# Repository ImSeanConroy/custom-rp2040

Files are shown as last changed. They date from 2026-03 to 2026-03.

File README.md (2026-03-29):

# Custom RP2040

Complete design files for an RP2040 microcontroller-based board, created using KiCad.

## Contributing

Contributions are welcome. Please open an issue or fork the repository, create a new branch (`feature/your-feature-name`) and submit a pull request for any enhancements or bug fixes.

## License

This project is licensed under the MIT License - see the [LICENSE](LICENSE) file for information.

## Support

If you are having problems, please let me know by [raising a new issue](https://github.com/ImSeanConroy/custom-rp2040/issues/new/choose).

## Acknowledgments

A special thanks to the creators of these invaluable resources that helped guide this project:

- [Custom RP2040 PCB Design in KiCAD](https://deepbluembedded.com/raspberry-pi-pico-rp2040-schematic-pcb-design-in-kicad/): Raspberry Pi Pico (RP2040) Schematic & PCB Design in KiCAD by Khaled Magdy
- [Hardware design for the RP2040](https://github.com/calliah333/RP2040-designguide/tree/main?tab=readme-ov-file#voltage-regulator): by calliah333

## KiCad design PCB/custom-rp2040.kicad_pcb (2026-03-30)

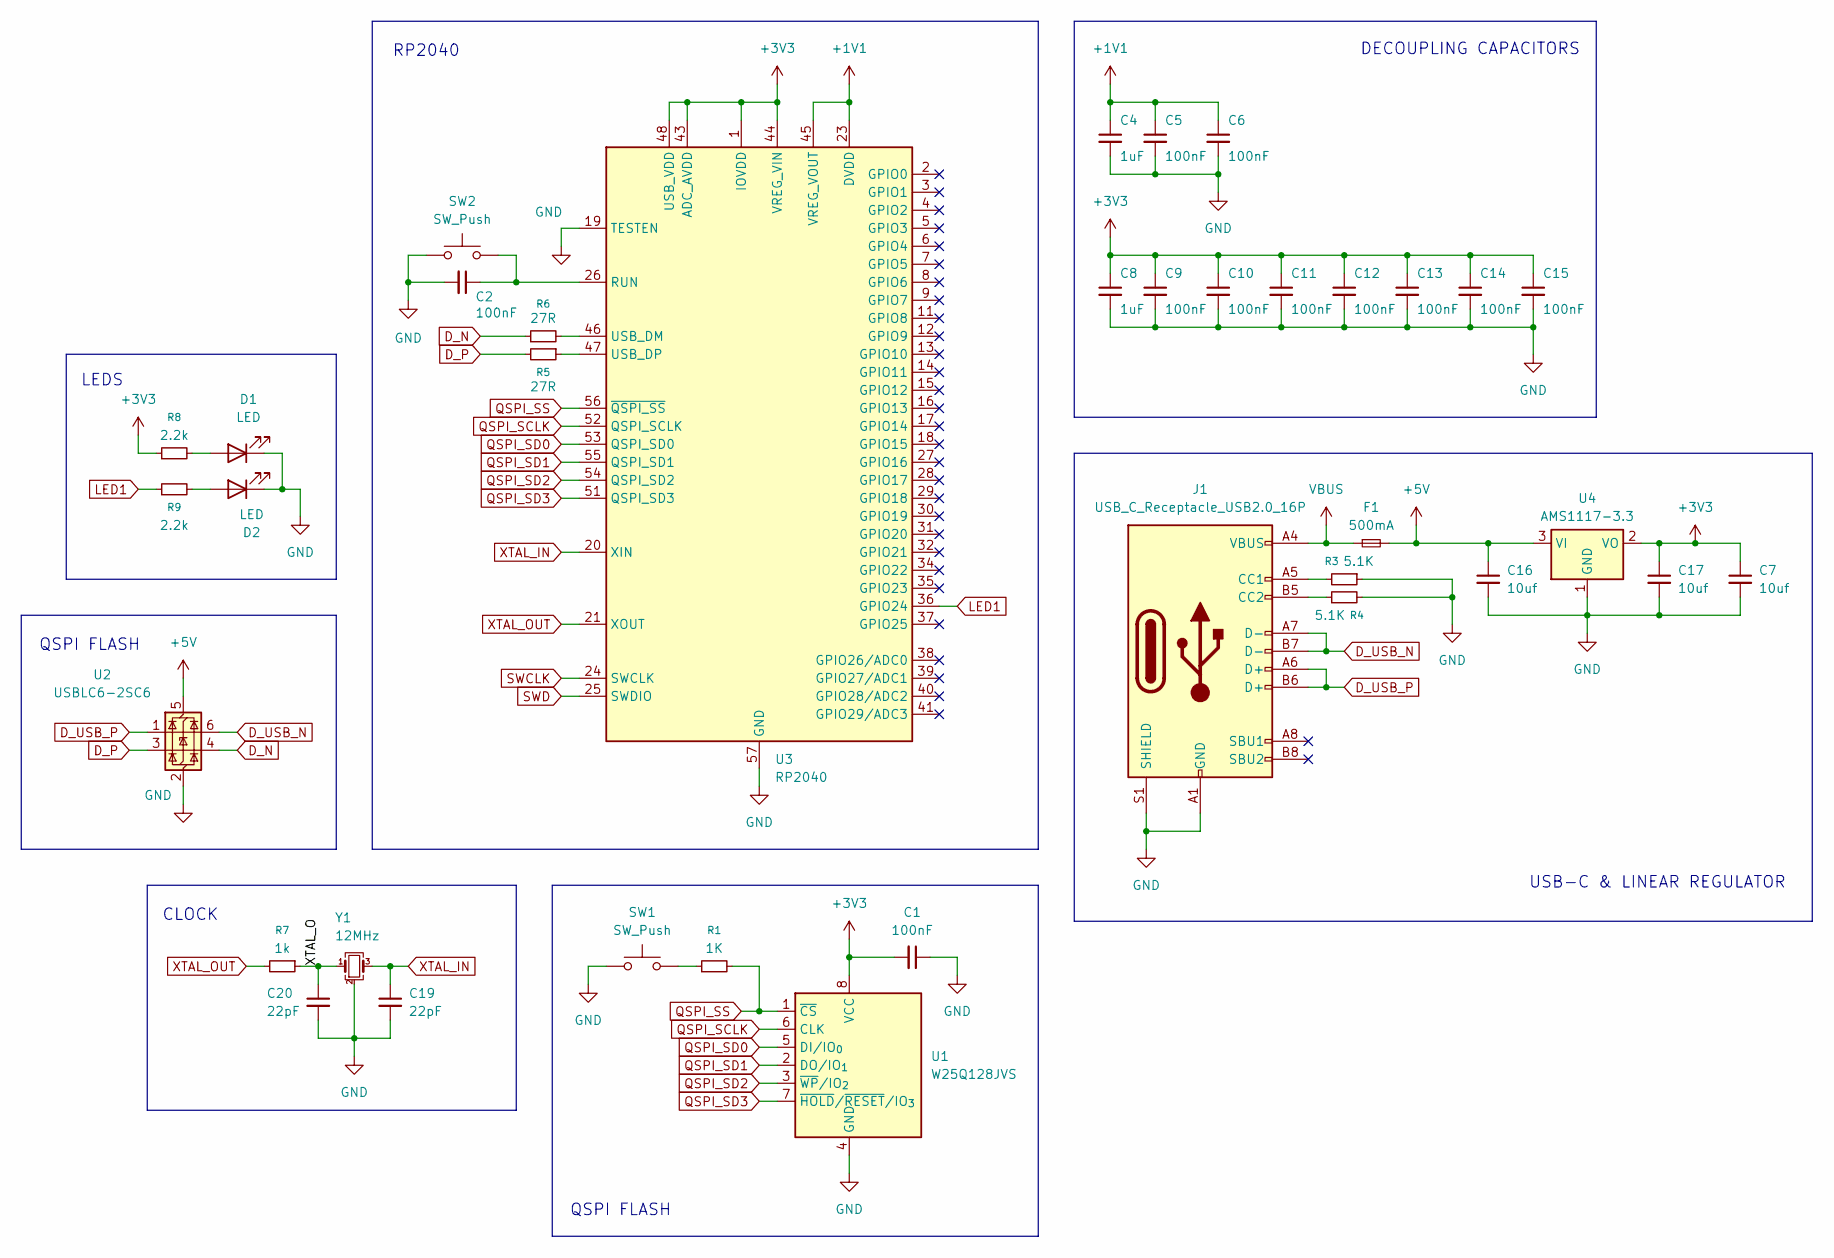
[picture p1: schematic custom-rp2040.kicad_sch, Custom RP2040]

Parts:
C1: 100nF; C_0402_1005Metric
C2, C5, C6, C9, C10, C11, C12, C13, C14, C15: 100nF; C_0402_1005Metric; LCSC C1525
C4, C8: 1uF; C_0402_1005Metric; LCSC C52923
C7, C16, C17: 10uf; C_0402_1005Metric
C19, C20: 22pF; C_0402_1005Metric
D1, D2: LED; LED_0402_1005Metric
F1: 500mA; Fuse_1206_3216Metric
J1: USB_C_Receptacle_USB2.0_16P; USB_C_Receptacle_HCTL_HC-TYPE-C-16P-01A
R1: 1K; R_0402_1005Metric
R3, R4: 5.1K; R_0402_1005Metric
R5, R6: 27R; R_0402_1005Metric
R7: 1k; R_0402_1005Metric
R8, R9: 2.2k; R_0402_1005Metric
SW1, SW2: SW_Push; SW_SPST_PTS810
U1: W25Q128JVS; SOIC-8_5.3x5.3mm_P1.27mm
U2: USBLC6-2SC6; SOT-23-6; LCSC C2827654
U3: RP2040; QFN-56-1EP_7x7mm_P0.4mm_EP3.2x3.2mm
U4: AMS1117-3.3; SOT-223-3_TabPin2
Y1: 12MHz; Crystal_SMD_3225-4Pin_3.2x2.5mm; LCSC C9002

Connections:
+1V1: C4.1, C5.1, C6.1, U3.23 (DVDD), U3.45 (VREG_VOUT), U3.50 (DVDD)
+3V3: C1.2, C7.1, C8.1, C9.1, C10.1, C11.1, C12.1, C13.1, C14.1, C15.1, C17.1, R8.1, U1.8 (VCC), U3.1 (IOVDD), U3.10 (IOVDD), U3.22 (IOVDD), U3.33 (IOVDD), U3.42 (IOVDD), U3.43 (ADC_AVDD), U3.44 (VREG_VIN), U3.48 (USB_VDD), U3.49 (IOVDD), U4.2 (VO)
+5V: C16.1, F1.2, U2.5 (VBUS), U4.3 (VI)
/XTAL_O: C20.1, R7.1, Y1.1
D_N: R6.1, U2.4 (I/O2)
D_P: R5.2, U2.3 (I/O2)
D_USB_N: J1.A7 (D-), J1.B7 (D-), U2.6 (I/O1)
D_USB_P: J1.A6 (D+), J1.B6 (D+), U2.1 (I/O1)
GND: C1.1, C2.2, C4.2, C5.2, C6.2, C7.2, C8.2, C9.2, C10.2, C11.2, C12.2, C13.2, C14.2, C15.2, C16.2, C17.2, C19.2, C20.2, D1.1 (K), D2.1 (K), J1.A1 (GND), J1.A12 (GND), J1.B1 (GND), J1.B12 (GND), J1.S1 (SHIELD), R3.1, R4.2, SW1.1, SW2.1, U1.4 (GND), U2.2 (GND), U3.19 (TESTEN), U3.57 (GND), U4.1 (GND), Y1.2 (G), Y1.4 (G)
LED1: R9.1, U3.36 (GPIO24)
unnamed: D1.2 (A), R8.2
unnamed: D2.2 (A), R9.2
unnamed: J1.A5 (CC1), R3.2
unnamed: J1.B5 (CC2), R4.1
unnamed: R1.1, SW1.2
unnamed: C2.1, SW2.2, U3.26 (RUN)
unnamed: R6.2, U3.46 (USB_DM)
unnamed: R5.1, U3.47 (USB_DP)
QSPI_SCLK: U1.6 (CLK), U3.52 (QSPI_SCLK)
QSPI_SD0: U1.5 (DI/IO_{0}), U3.53 (QSPI_SD0)
QSPI_SD1: U1.2 (DO/IO_{1}), U3.55 (QSPI_SD1)
QSPI_SD2: U1.3 (~WP/IO_{2}), U3.54 (QSPI_SD2)
QSPI_SD3: U1.7 (~HOLD/~RESET/IO_{3}), U3.51 (QSPI_SD3)
QSPI_SS: R1.2, U1.1 (~CS), U3.56 (~QSPI_SS)
SWCLK: U3.24 (SWCLK)
SWD: U3.25 (SWDIO)
VBUS: F1.1, J1.A4 (VBUS), J1.A9 (VBUS), J1.B4 (VBUS), J1.B9 (VBUS)
XTAL_IN: C19.1, U3.20 (XIN), Y1.3
XTAL_OUT: R7.2, U3.21 (XOUT)

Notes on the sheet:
RP2040
DECOUPLING CAPACITORS
LEDS
USB-C & LINEAR REGULATOR
QSPI FLASH
CLOCK

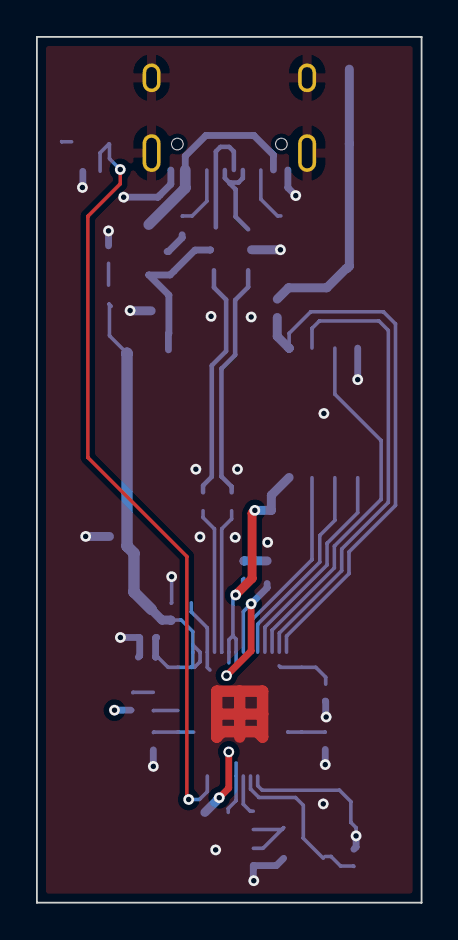
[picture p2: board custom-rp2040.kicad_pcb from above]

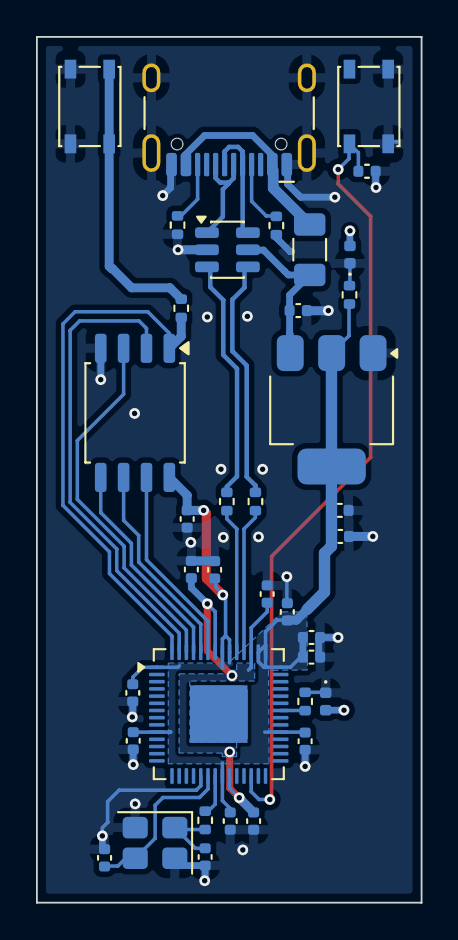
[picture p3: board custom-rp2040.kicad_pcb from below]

Board: 2 copper layers, 21.4 x 48.1 mm, 37 parts (37 on the bottom side), 27 nets.

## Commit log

2026-03-29 Layout schematic
    [custom-rp2040.kicad_pcb, custom-rp2040.kicad_sch]
2026-03-29 Layout board
    [custom-rp2040.kicad_pcb, custom-rp2040.kicad_sch]
2026-03-30 Add reset and boot buttons
    [custom-rp2040.kicad_pcb, custom-rp2040.kicad_sch]
